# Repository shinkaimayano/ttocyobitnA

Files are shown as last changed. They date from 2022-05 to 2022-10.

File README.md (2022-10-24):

# ttocyobitnA

ttocyobitnA (or Antiboycott) is a drop-in PCB for [Ttocyobitna](https://trashman.wiki/en/keyboards/ttocyobitna) with support for multiple layouts.

The original was made by [Trash Man](https://trashman.club/) while under the alias of Pycki47.
The open sourced files for it can be found [here](https://github.com/evangs/ttocyobitna).

## Status

**Currently Untested.** ***Order at your own risk.***

Note: JLCPCB may not have a preview show since they struggle to render hatched fills. It was able to render with a solid fill though so it should be fine.

Dimensions: 266.67mm x 76.17mm

Firmware can be found [here](https://github.com/shinkaimayano/Firmwares).

## Changes

- General Cleanup
  - Makes use of more default KiCad 6 libraries
    - Only external libraries used are [marbastlib](https://github.com/ebastler/marbastlib) and [ai03's Switch Symbol](https://github.com/ai03-2725/MX_Alps_Hybrid)
  - Organized files and folders
    - Removed old libraries and footprints
- Redone Eeschema
  - Switched to a USB-C 2.0 symbol
  - Tray mount holes are now included in the schematic
  - More clear labeling of the switch matrix
- Revamped PCBNew
  - Rerouted with curved traces and changed to a hatched GND fill
  - Capacitors and resistors have been changed to a smaller footprint (0605 &rarr; 0402)
  - Replaced the 1uF capacitor for a 10uF on the VBUS line
    - This is recommended by the 32U4 datasheet (Section 21.5)
  - Replaced the TVS diodes with a SRV05-4
  - Switched the USB-C footprint to the more common HRO-M-12
  - Added two extra 100nF decoupling capacitors
  - Added a 1k&Omega; resistor to the crystal to protect it from being over-driven
  - Added an ISP breakout
    - Also acts as an RGB strip breakout (top pads)
    - Removed reset button as a result
  - Proper shield implementation (4.7nF capacitor, 1M&Omega; resistor, and a screw hole connected to Earth)
- More layout options (see [KLE](http://www.keyboard-layout-editor.com/#/gists/c1b2365e78564452fc1ebb7e3b01f5bb))
  - Added silkscreen text to explicitly show mod size and layout options
  - Rotary encoder support in the top right as well as 1u/1.5u
  - Stepped caps-lock support
    - Supports 3.0mm THT LED indicator
  - Full right shift support (2.75u)
  - 6.25u Spacebar bottom rows
  
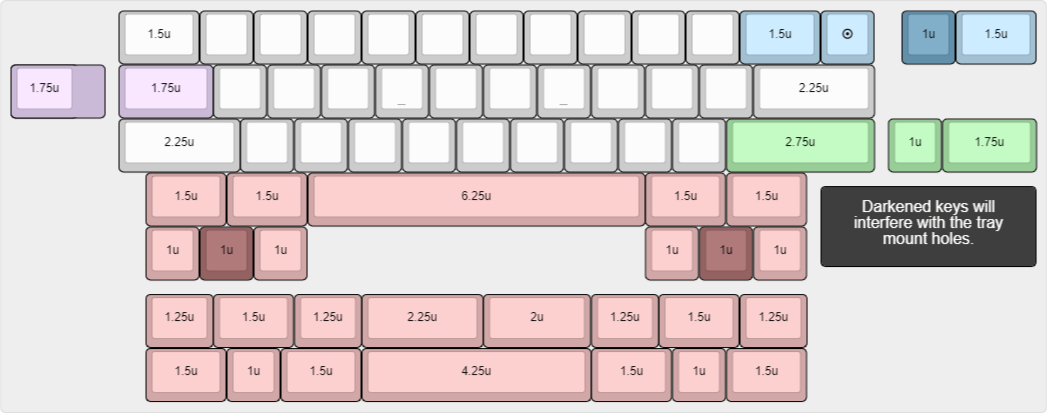
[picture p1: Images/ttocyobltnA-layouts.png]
KLE


## Renders

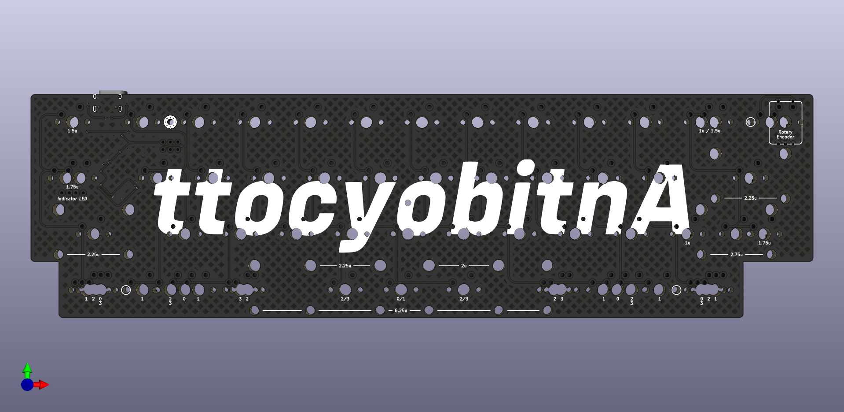
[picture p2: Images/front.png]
Front


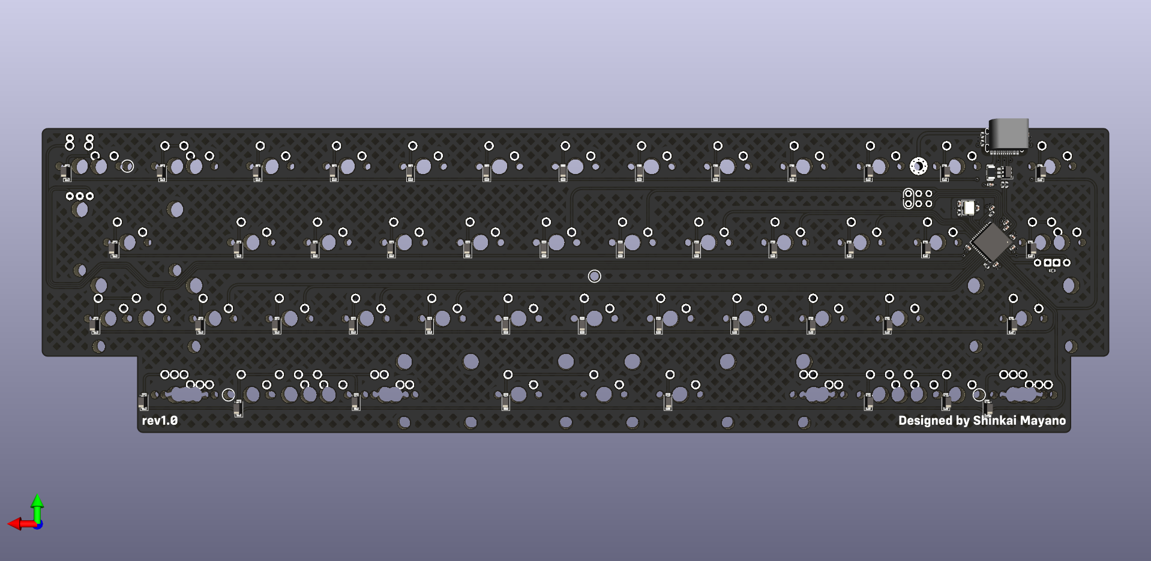
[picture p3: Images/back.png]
Back


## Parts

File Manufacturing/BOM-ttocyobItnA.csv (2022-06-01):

Comment | Designator | Footprint | LCSC
1k | R4,R9 | R_0402_1005Metric | C11702
16MHz | Y1 | Crystal_SMD_3225-4Pin_3.2x2.5mm | C13738
100nF | C10,C5,C6,C7,C8,C9 | C_0402_1005Metric | C1525
4.7nF | C11 | C_0402_1005Metric | C1538
10uF | C4 | C_0402_1005Metric | C15525
22pF | C2,C3 | C_0402_1005Metric | C1555
HRO-M-12 | USB1 | USB_C_Receptacle_HRO_TYPE-C-31-M-12 | C167321
22 | R1,R2 | R_0402_1005Metric | C25092
10k | R3,R5 | R_0402_1005Metric | C25744
5.1k | R6,R7 | R_0402_1005Metric | C25905
1M | R8 | R_0402_1005Metric | C26083
32U4-MU | U1 | QFN-44-1EP_7x7mm_P0.5mm_EP5.2x5.2mm | C45874
1uF | C1 | C_0402_1005Metric | C52923
500mA | F1 | Fuse_1206_3216Metric | C70076
D_Small | D1,D10,D11,D12,D13,D14,D15,D16,D17,D18,D19,D2,D20,D21,D22,D23,D24,D25,D26,D27,D28,D29,D3,D30,D31,D32,D33,D34,D35,D36,D37,D38,D39,D4,D40,D41,D42,D43,D44,D45,D5,D6,D7,D8,D9 | D_SOD-123 | C81598
SRV05-4 | U2 | SOT-23-6-routable | C85364

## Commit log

2022-05-30 ああああ
2022-05-30 ああああああ
2022-05-30 あああああああ
2022-05-31 ああああああああ
    [ttocyobItnA-B_Cu.gbr, ttocyobItnA-B_Mask.gbr, ttocyobItnA-B_Silkscreen.gbr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]
